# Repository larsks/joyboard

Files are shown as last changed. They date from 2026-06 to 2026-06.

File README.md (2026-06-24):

# Joyboard -- the joystick that thinks its a keyboard

I built a weird little joystick that runs [QMK] that can be used to control your computer, navigate your browser, or play your favorite vintage video game.

[qmk]: https://qmk.fm/

## Overview

The joyboard consists of a joystick, two rotary encoders (with pushbuttons), four arcade buttons, and two 3-way rocker switches.

## Parts list

| Quantity | Item |
| --- | --- |
| 1 | [160mmx110mmx90mm project box](https://a.co/d/0czWrPIz) |
| 2 | [Snap-in round momentary rocker switch](https://a.co/d/0cHW5Blm) |
| 2 | [Aluminum knob](https://a.co/d/036jfmPl)
| 2 | [EC11 rotary encoder](https://a.co/d/08Swv7bY) |
| 4 | [24mm arcade buttons](https://a.co/d/00qQOsl5) |
| 1 | [Seimitsu LS-40 Joystick][joystick] |
| 1 | [Waveshare RP2040-Zero](https://www.waveshare.com/rp2040-zero.htm) |
| 1 | [D-type USB C panel mount](https://a.co/d/0aqtTgPk) |

[joystick]: https://paradisearcadeshop.com/collections/seimitsu-ls-40-series/products/seimitsu-ls-40-01-se-joystick-black

## Pin assignments

```
                      ┌───┐
            5V ─── ┌──└───┘──┐ ─── GP0 BUTTON3
           GND ─── │   USB   │ ─── GP1 BUTTON2
            3V ─── │         │ ─── GP2 ENC0-A
BUTTON1   GP29 ─── │         │ ─── GP3 ENC0-B
BUTTON0   GP28 ─── │         │ ─── GP4 ENC0-Switch
TOGGLE1-A GP27 ─── │         │ ─── GP5 ENC1-A
TOGGLE1-B GP26 ─── │         │ ─── GP6 ENC1-B
TOGGLE0-A GP15 ─── │         │ ─── GP7 ENC1-Switch
TOGGLE0-B GP14 ─── └┬─┬─┬─┬─┬┘ ────GP8
                    │ │ │ │ │
                    │ │ │ │ │
                    G G G G G
                    P P P P P
                    1 1 1 1 9
                    3 2 1 0

           JOYSTICK - U D R L        
```

## Layout

You can find `.dxf` drawings of the Joyboard in the [panel/](panel/) directory. There is also an A2-sized [PDF] of the front, side, and rear layout.

[pdf]: panel/combined.pdf

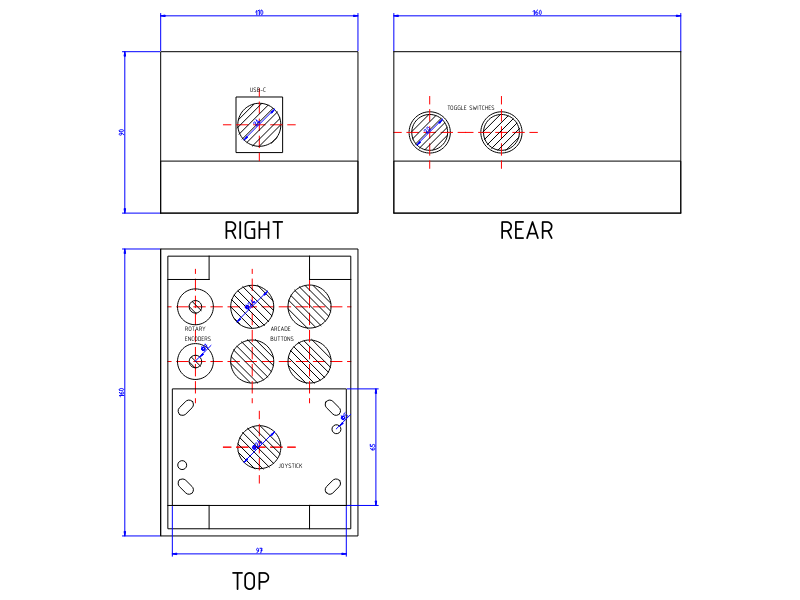
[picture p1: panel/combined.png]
CAD drawing with joystick on the left


## Rendered images

Front view:

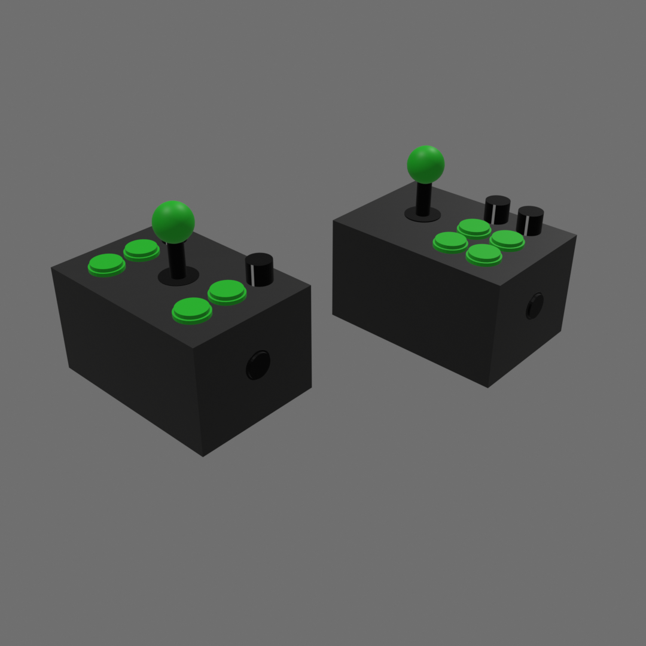
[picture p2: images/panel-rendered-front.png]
Rendered front view showing both panel layouts


Rear view:

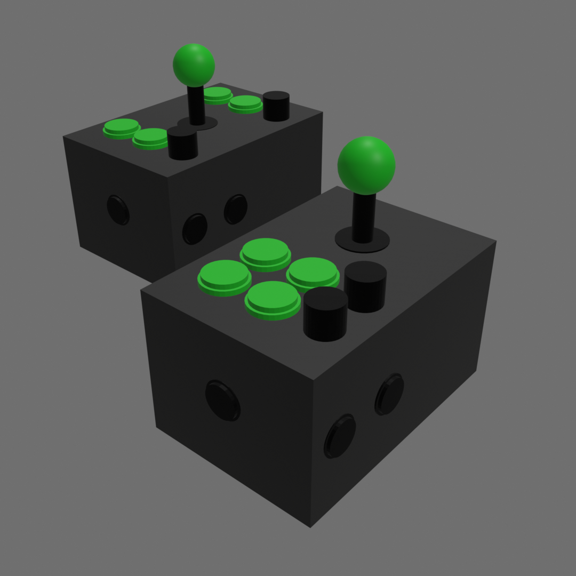
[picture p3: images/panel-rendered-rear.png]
Rendered rear view showing both panel layouts


## Finished project

Front view:

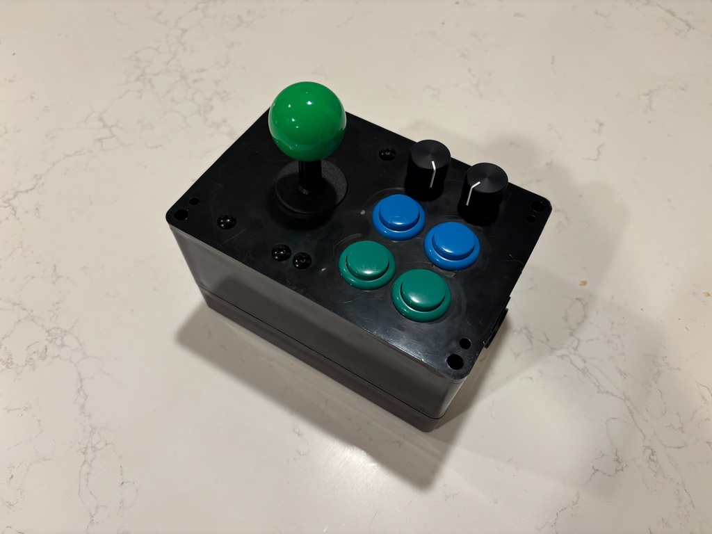
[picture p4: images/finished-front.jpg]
Photograph of the joyboard from the front


Rear view:

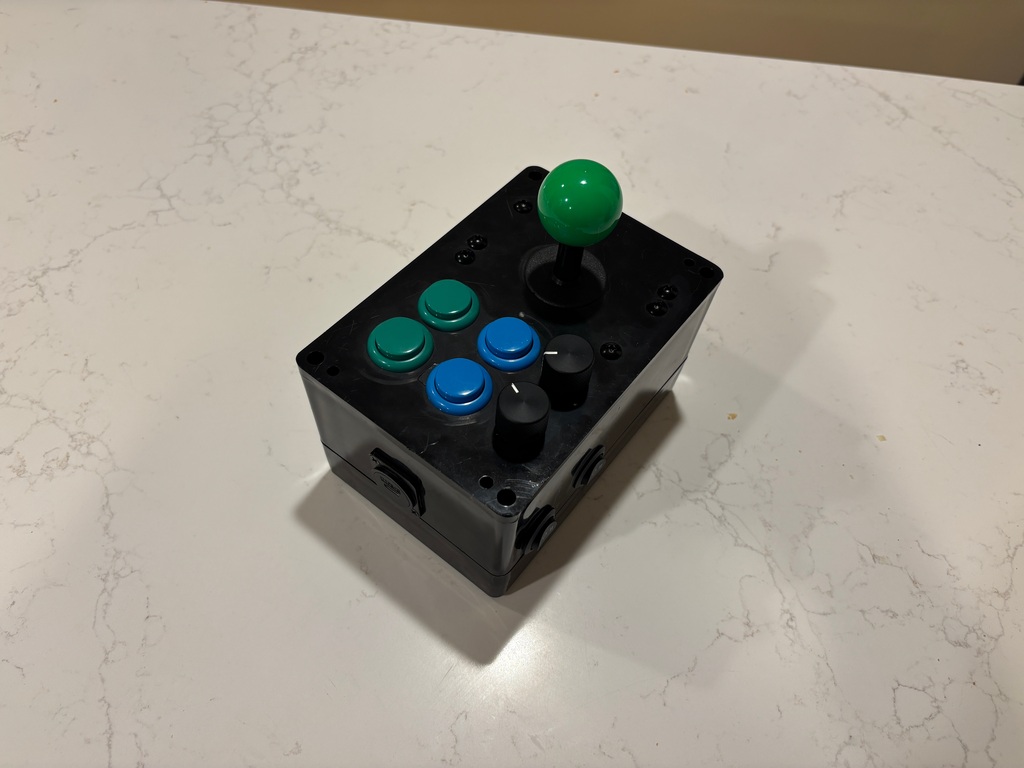
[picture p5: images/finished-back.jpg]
Photograph of the joyboard from the back


## Firmware

To compile the firmware, run:

```sh
bash compile.sh
```

After placing the joyboard in BOOTSEL mode (entering bootsel mode), you can install new firmware by running:

```sh
bash install.sh
```

### Entering BOOTSEL mode

There are two ways to enter bootsel mode:

1. Hold down `BUTTON0` (upper left button) when plugging in the joyboard.

2. While the joyboard is powered on, press both encoders down at the same time.

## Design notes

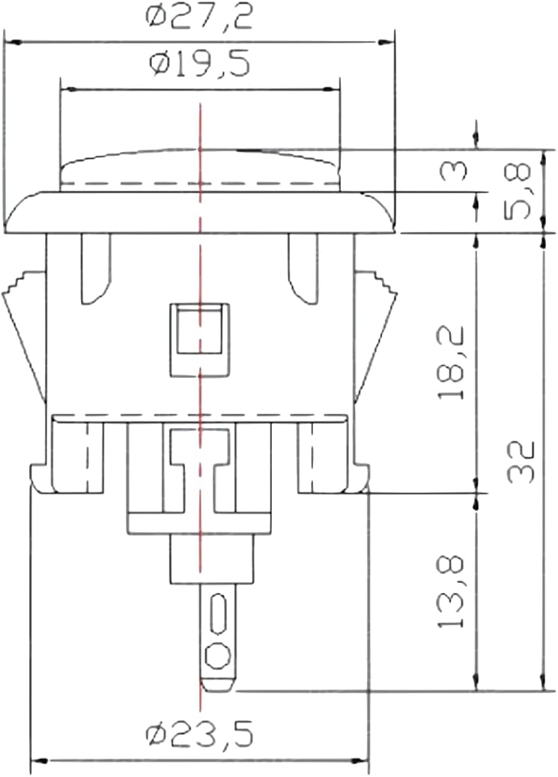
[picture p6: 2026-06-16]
panel/sanwa_24mm_button.jpg

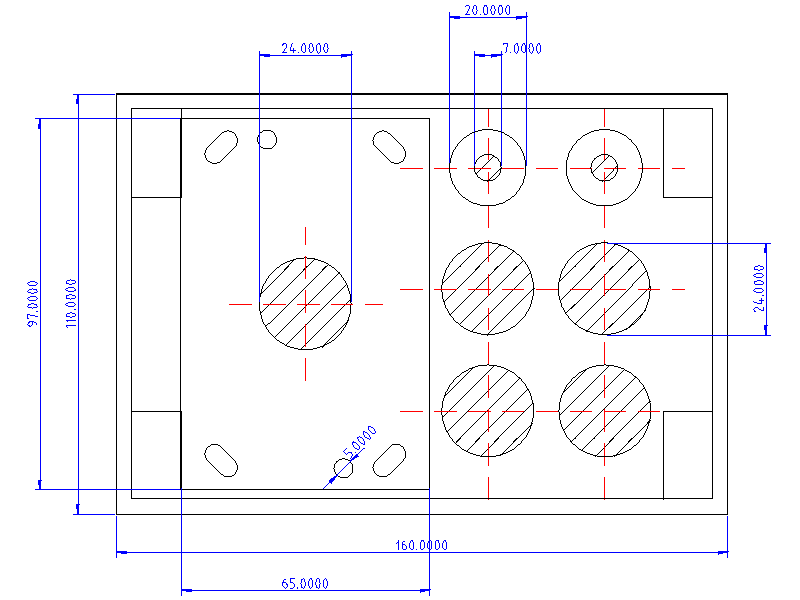
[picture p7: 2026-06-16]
panel/control_layout_joystick_left.png

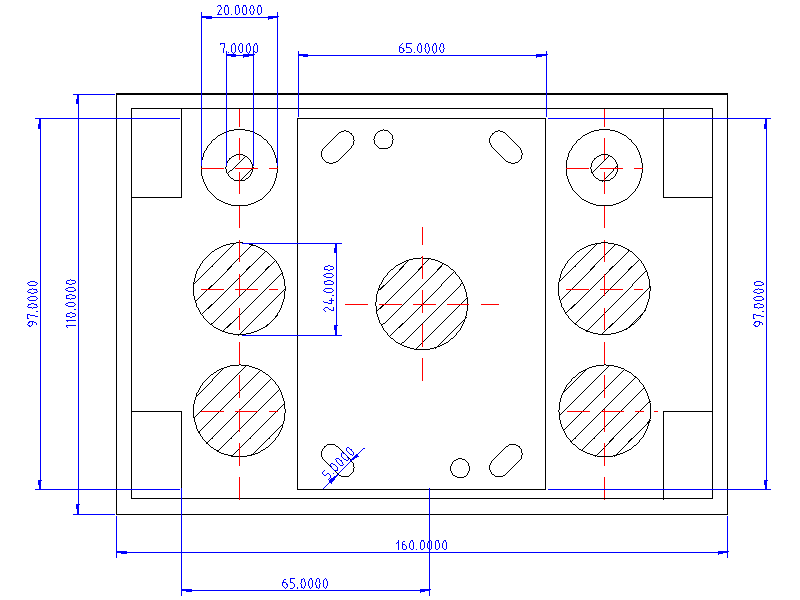
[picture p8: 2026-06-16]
panel/control_layout_joystick_center.png

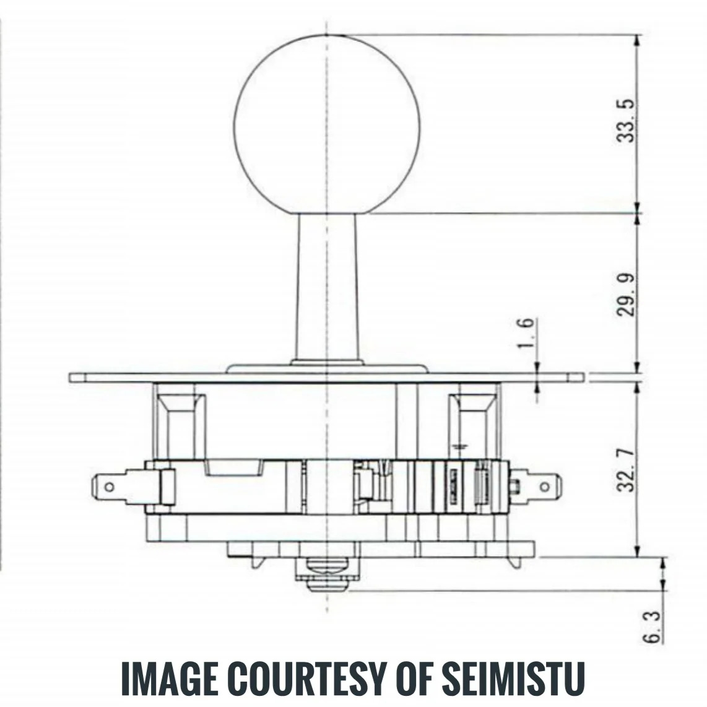
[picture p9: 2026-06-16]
panel/seimitsu_ls40_joystick.jpg

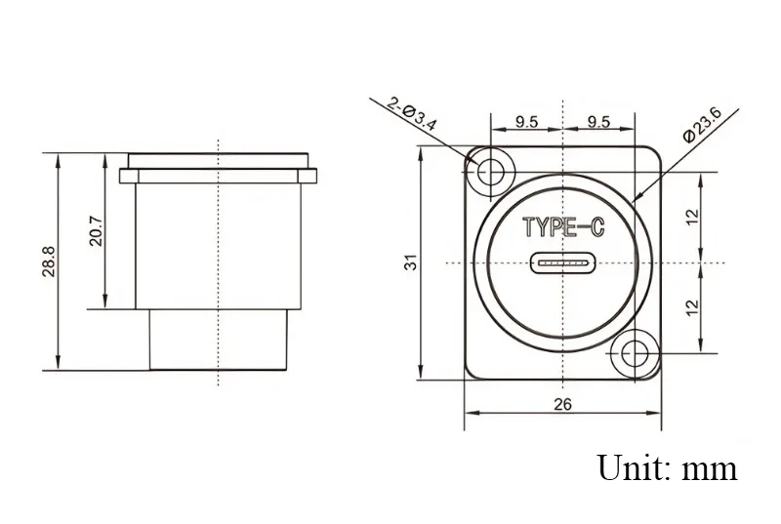
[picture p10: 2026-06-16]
panel/usb-c-passthrough.png

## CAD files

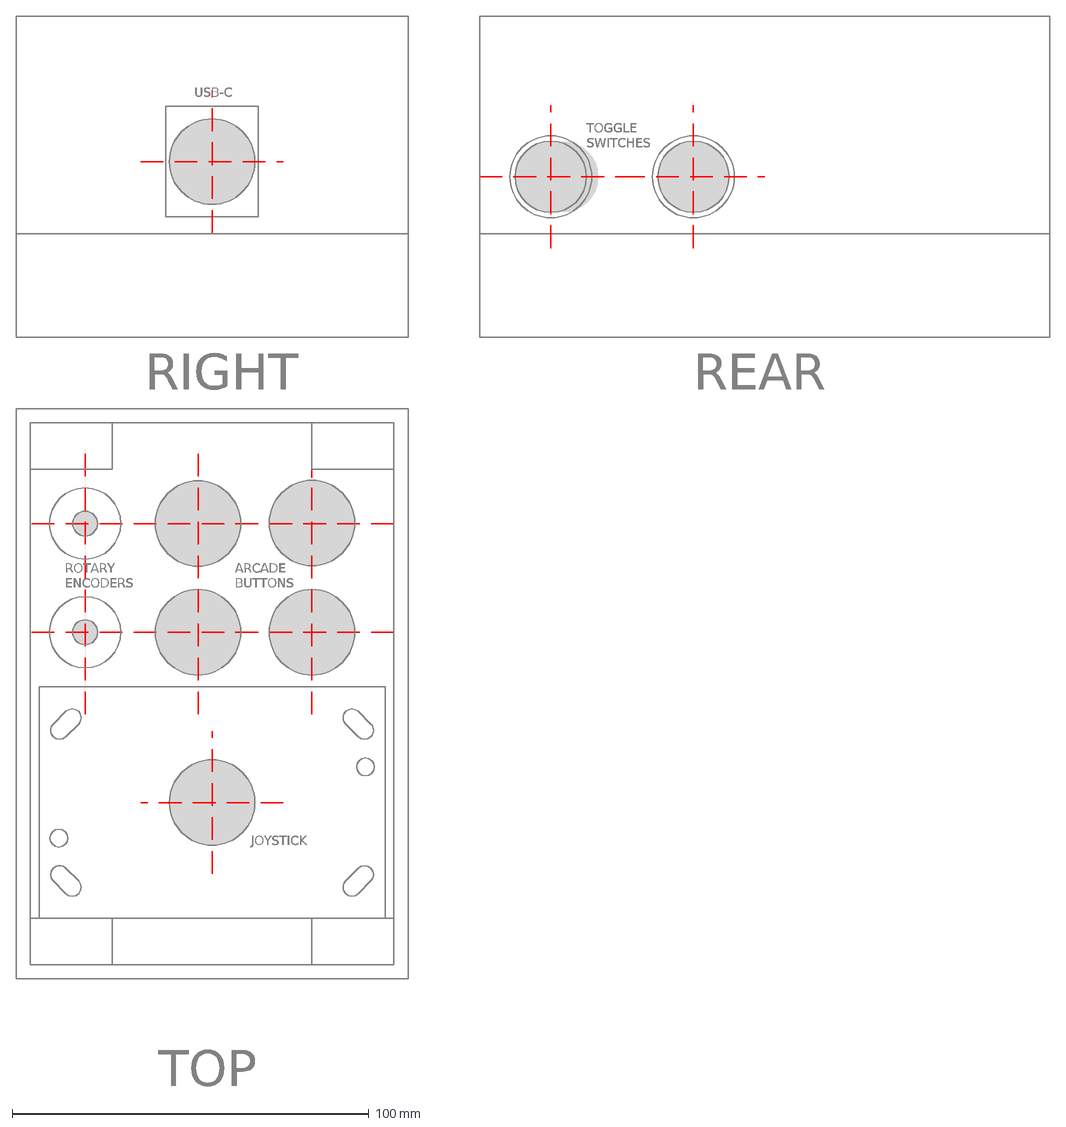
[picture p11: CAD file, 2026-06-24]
panel/combined.dxf
RIGHT
REAR
TOP
USB-C
TOGGLE SWITCHES
JOYSTICK
ARCADE BUTTONS
ROTARY ENCODERS

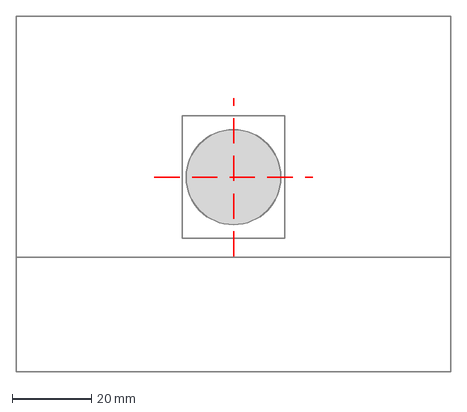
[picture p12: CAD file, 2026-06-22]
panel/side-usb.dxf
110.0 x 90.0 mm

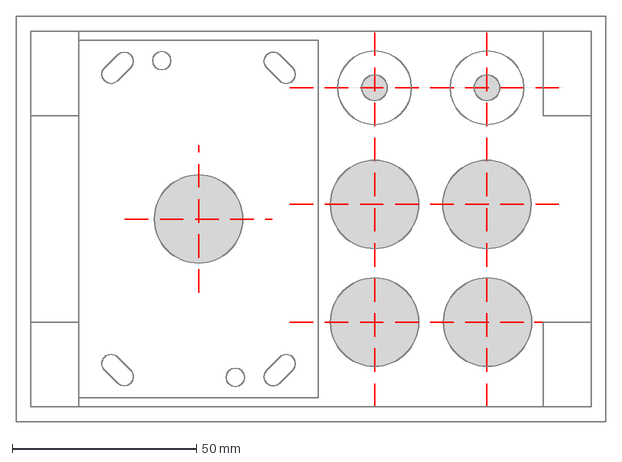
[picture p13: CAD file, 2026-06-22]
panel/control_layout_joystick_left.dxf
160.0 x 110.0 mm

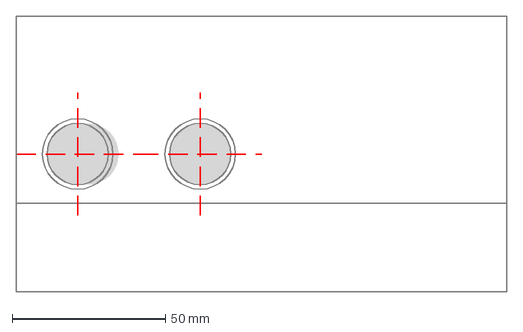
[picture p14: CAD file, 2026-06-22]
panel/back-toggle-switches.dxf
160.0 x 90.0 mm

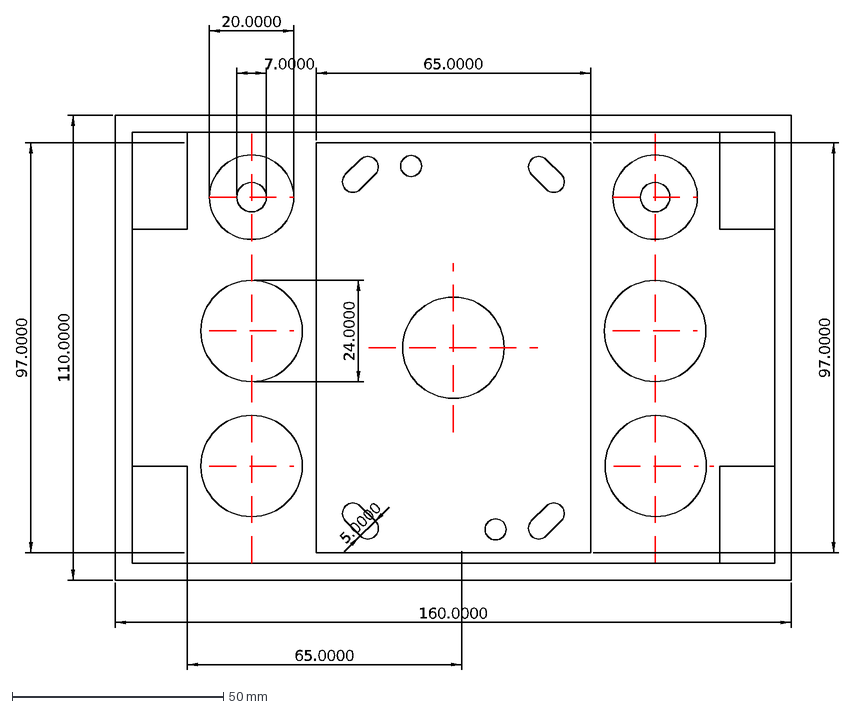
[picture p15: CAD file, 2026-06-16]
panel/control_layout_joystick_center.dxf
65.0000
97.0000
5.0000
110.0000
160.0000
24.0000
20.0000
7.0000

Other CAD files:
panel/panel.blend

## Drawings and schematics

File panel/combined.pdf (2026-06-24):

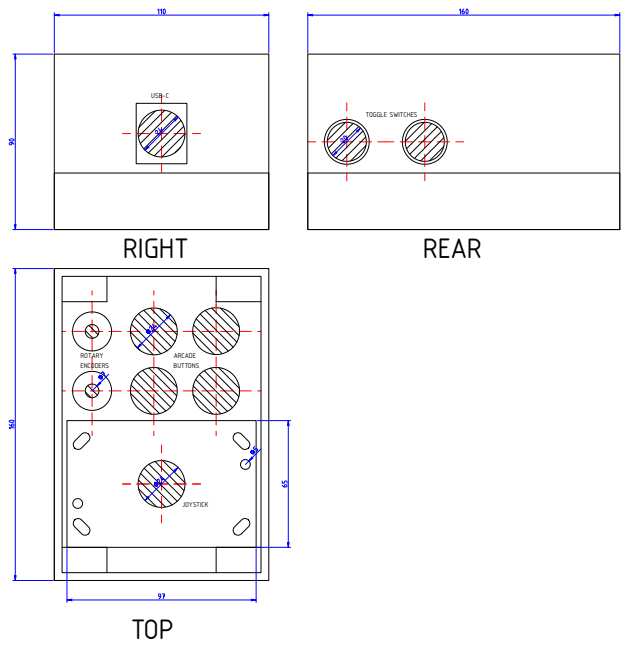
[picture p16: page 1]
RIGHT; REAR; TOP; USB-C; TOGGLE SWITCHES; JOYSTICK; ARCADE BUTTONS; ROTARY ENCODERS

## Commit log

2026-06-16 Joystick keyboard initial commit
    [control_layout_joystick_center.dxf, control_layout_joystick_left.dxf, panel.blend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]
2026-06-16 fix: Update pin assignments
    Now that we have a prototype, replace placeholder assignments with actual
    pin connections.
2026-06-16 feat: Add toggle switches
2026-06-16 fix: Remove unused LED code
    Previously we were using the LED to provide layer information, but with the
    LED inside a box nobody can see it.
2026-06-22 cad: Relocate toggle switches to back
    The joystick takes up too much space for the original layout to work. I
    think if we put the toggle switches on the back and the usb passthrough on
    the side things should work out.
    [back-toggle-switches.dxf, side-usb.dxf, sides.dxf]
2026-06-22 cad: Relocate some measurements
    [control_layout_joystick_left.dxf]
2026-06-22 feat: Enable bootmagic
    Hold down what the key at matrix position (0,0) at boot to put the RP2040
    in bootsel mode. For the current mappings, this means `BUTTON1`.
2026-06-22 fix: Update keyboard.json to match actual wiring
2026-06-22 feat: Implement next/previous layer support
    Replace earlier use of explicit TO() calls.
    We also clean up process_record_user a bit, and add a "show layer" function
    (press the blue buttons simultaneously to type out the current layer
    number).
2026-06-22 feat: Make second encoder control mic gain
2026-06-22 refactor: Replace encoder_map with encoder_update_user()
    The encoder map array required one entry per layer despite all layers
    having identical mappings. Replace it with encoder_update_user() which
    handles encoder events directly, eliminating the need to keep the
    encoder map in sync when layers change.
2026-06-22 chore: Add watch-events.sh script
    `scripts/watch-events.sh` uses udevadm to discover all the input devices
    associated with the joyboard, and then spawns evsieve to view all events
    from the joyboard.
    Pass -g/--grab if you want watch-events to have exclusive access to the
    devices.
2026-06-22 feat: Improvements to niri and browser layers
    - Add mappings for arcade buttons in both layers
    - Use enum to manage layer ordering
2026-06-22 cad: New renderings showing updated design
    [combined.dxf, panel.blend]
2026-06-24 docs: Add photographs and pdf
    - Add photographs of the finished project
    - Add A2-sized PFD export of the front, rear, and side panel layouts
    [combined.dxf]
